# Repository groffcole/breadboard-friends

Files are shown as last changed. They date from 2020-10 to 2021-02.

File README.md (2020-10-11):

breadboard-friends
==================

A collection of cute breakout boards riding solderless breadboards, mostly for analog audio works

These PCB layouts and schematics are released under a Creative Commons cc-by-sa
3.0 license.

NOTE: This is a forked version of breadboard-friends and has two main differences from the original:
- There are two additional BBFs, one using Thonkiconn 3.5mm Jacks (bbf-thonkjacks) and another providing eurorack header with polarity protection for providing eurorack power to your breadboard from euro bus (bbf-europower). 
- This version has been updated to fit the power rails of the breadboards produced by [Assembly Specialist](http://www.assemblyspecialist.com/). The Assembly Specialist breadboard power rails have a wider spacing between them so the original BBFs do_not fit. Instead of 2x 10 pin DIL male headers for the power rails, use 4x 5 pin SIL male headers.

BBF-EUROPOWER Bill Of Materials (BOM)

- 2x 200ma PTC Poly Fuse or equivalent (or jumper wires if no fuse is required);
- 2x 10uF 25V Electrolytic Caps;
- 2x 1N5818 diodes or equivalent;
- 2x Ferrite Beads;
- 2x 10 Pin DIL male headers;
- 4x 5 pin SIL male headers.

BBF-THONKJACKS Bill Of Materials (BOM)

- 4x Thonkiconn Jacks;
- 1x 8 pin SIL female header;
- 4x 5 pin SIL male headers.

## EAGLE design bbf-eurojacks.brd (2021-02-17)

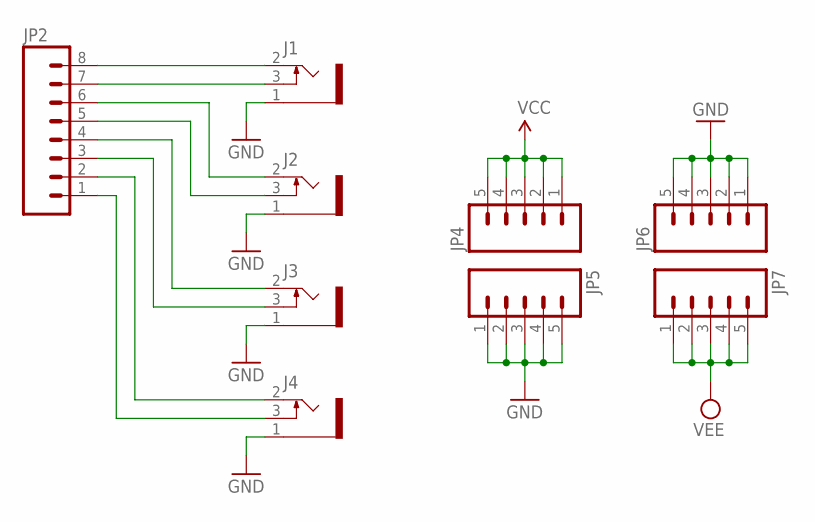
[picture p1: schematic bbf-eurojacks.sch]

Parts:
J1, J2, J3, J4: 1502_03SLOTTED; 1502_03_SLOTTED
JP2: M08; 1X08
JP4, JP5, JP6, JP7: M05PTH; 1X05

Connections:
GND: J1.1, J2.1, J3.1, J4.1, JP5.1, JP5.2, JP5.3, JP5.4, JP5.5, JP6.1, JP6.2, JP6.3, JP6.4, JP6.5
unnamed: J2.2, JP2.6
unnamed: J2.3, JP2.5
unnamed: J3.2, JP2.4
unnamed: J3.3, JP2.3
unnamed: J4.2, JP2.2
unnamed: J4.3, JP2.1
unnamed: J1.2, JP2.8
unnamed: J1.3, JP2.7
VCC: JP4.1, JP4.2, JP4.3, JP4.4, JP4.5
VEE: JP7.1, JP7.2, JP7.3, JP7.4, JP7.5

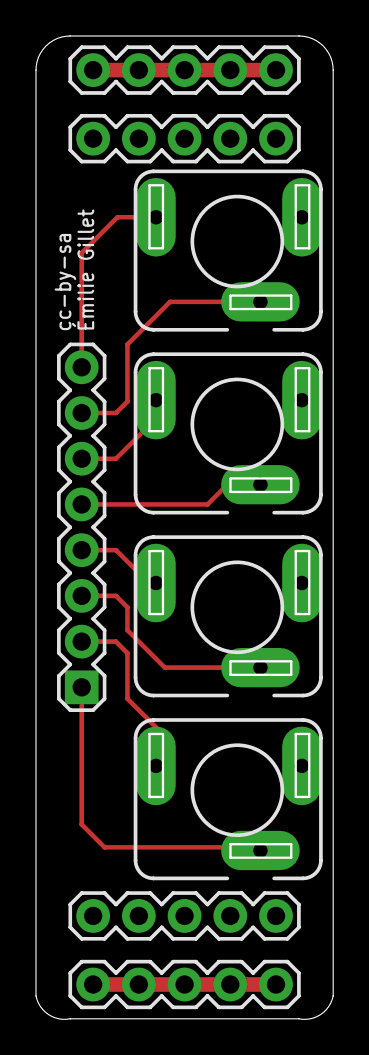
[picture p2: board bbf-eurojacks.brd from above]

Board: 2 copper layers, 16.5 x 54.6 mm, 9 parts (0 on the bottom side), 11 nets.

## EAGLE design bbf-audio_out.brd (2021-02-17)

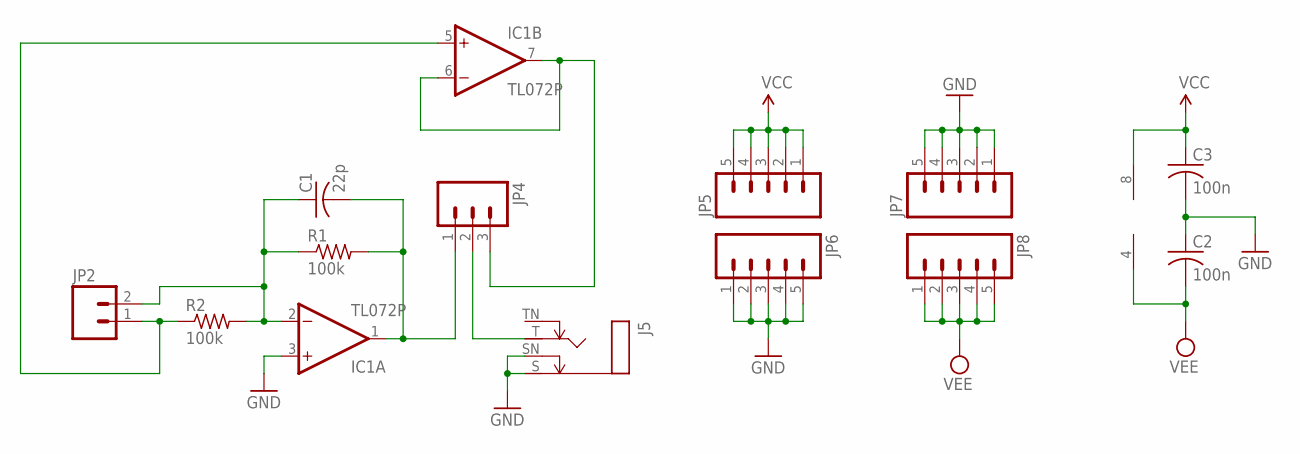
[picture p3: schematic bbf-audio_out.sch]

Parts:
C1: 22p; C025-025X050
C2, C3: 100n; C025-025X050
IC1: TL072P; DIL08
J5: MONOSWSLIM; NRJ4HF
JP2: M02PTH; 1X02
JP4: M03PTH; 1X03
JP5, JP6, JP7, JP8: M05PTH; 1X05
R1, R2: 100k; 0204/7

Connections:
GND: C2.1, C3.2, IC1.3 (+IN), J5.S, J5.SN, JP6.1, JP6.2, JP6.3, JP6.4, JP6.5, JP7.1, JP7.2, JP7.3, JP7.4, JP7.5
unnamed: C1.1, IC1.2 (-IN), JP2.2, R1.1, R2.2
unnamed: C1.2, IC1.1 (OUT), JP4.1, R1.2
unnamed: J5.T, JP4.2
unnamed: IC1.5 (+IN), JP2.1, R2.1
unnamed: IC1.6 (-IN), IC1.7 (OUT), JP4.3
VCC: C3.1, IC1.8 (V+), JP5.1, JP5.2, JP5.3, JP5.4, JP5.5
VEE: C2.2, IC1.4 (V-), JP8.1, JP8.2, JP8.3, JP8.4, JP8.5

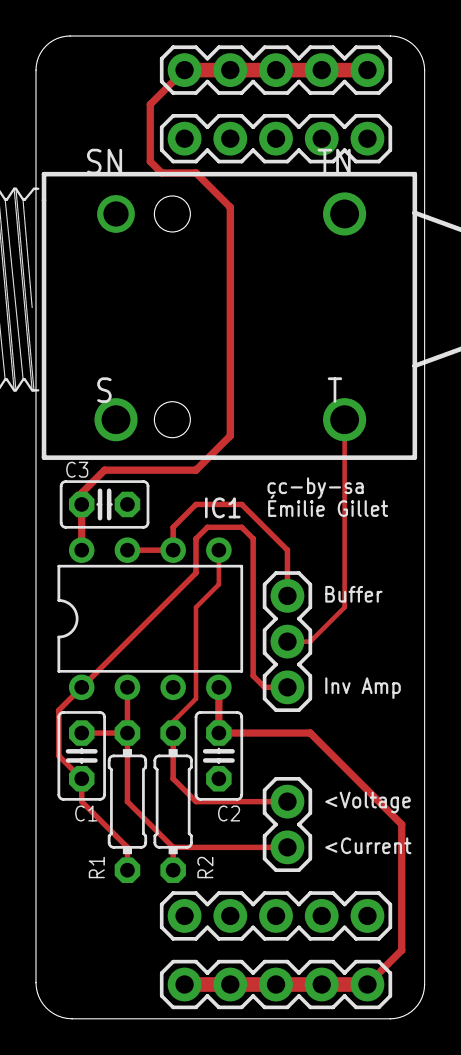
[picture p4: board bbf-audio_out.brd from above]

Board: 2 copper layers, 21.6 x 54.6 mm, 13 parts (0 on the bottom side), 8 nets.

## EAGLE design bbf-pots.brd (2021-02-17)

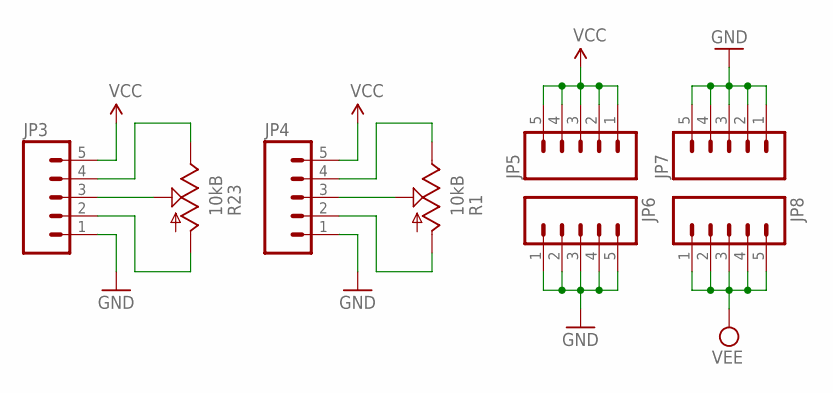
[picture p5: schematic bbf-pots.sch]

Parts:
JP3, JP4, JP5, JP6, JP7, JP8: M05PTH; 1X05
R1, R23: 10kB; ALPS_POT_VERTICAL

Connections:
GND: JP3.1, JP4.1, JP6.1, JP6.2, JP6.3, JP6.4, JP6.5, JP7.1, JP7.2, JP7.3, JP7.4, JP7.5
unnamed: JP3.4, R23.P$1 (E)
unnamed: JP3.3, R23.P$2 (S)
unnamed: JP3.2, R23.P$3 (A)
unnamed: JP4.4, R1.P$1 (E)
unnamed: JP4.3, R1.P$2 (S)
unnamed: JP4.2, R1.P$3 (A)
VCC: JP3.5, JP4.5, JP5.1, JP5.2, JP5.3, JP5.4, JP5.5
VEE: JP8.1, JP8.2, JP8.3, JP8.4, JP8.5

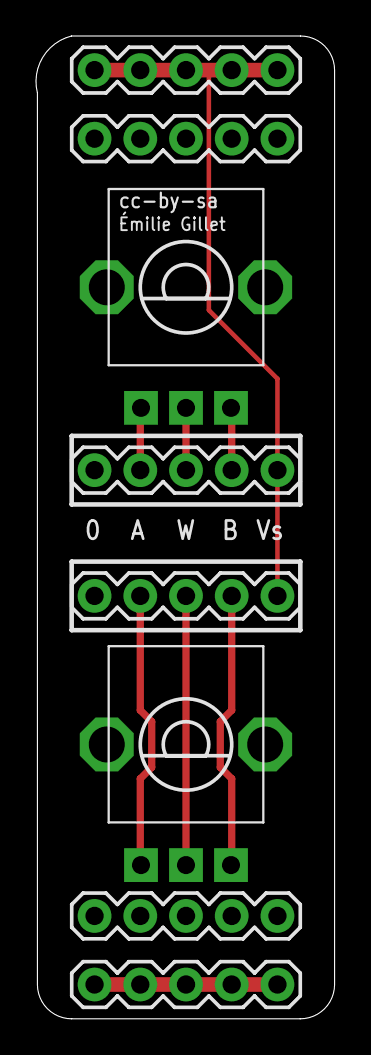
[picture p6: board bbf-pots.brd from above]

Board: 2 copper layers, 16.6 x 54.6 mm, 8 parts (0 on the bottom side), 9 nets.

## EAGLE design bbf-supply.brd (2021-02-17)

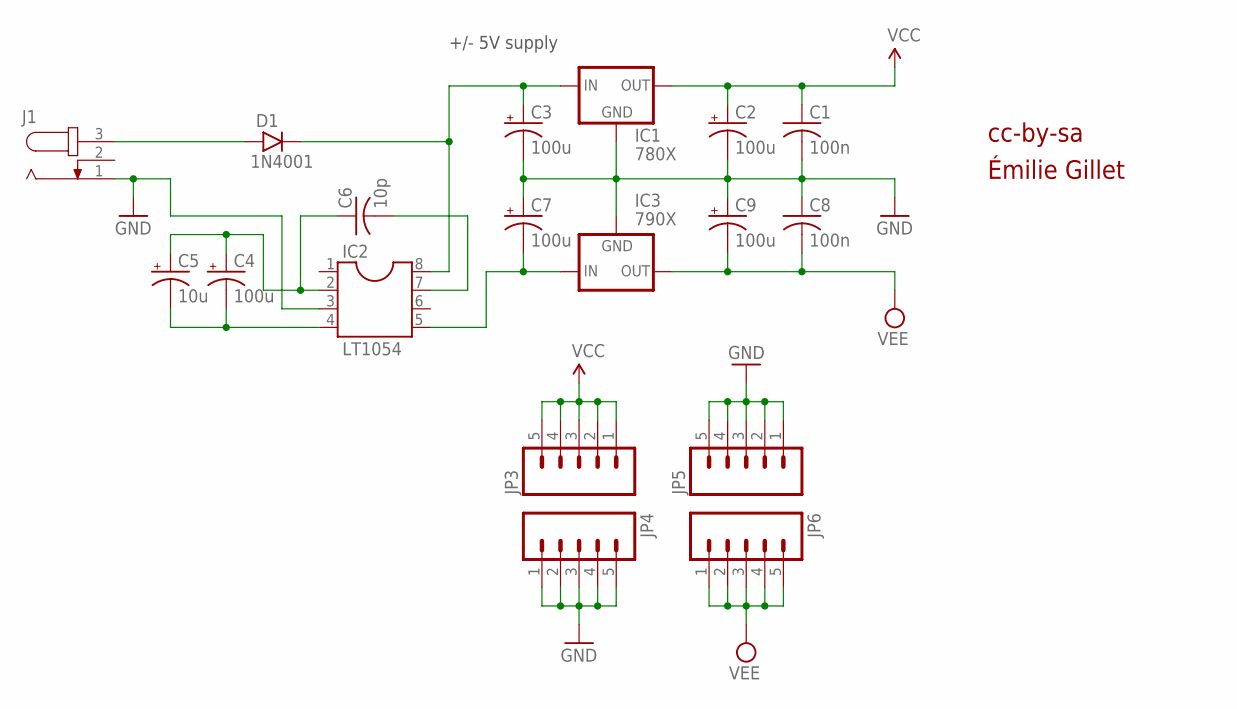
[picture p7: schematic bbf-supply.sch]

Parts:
C1, C8: 100n; C025-025X050
C2, C3, C7, C9: 100u; E2,5-7
C4: 100u; E2,5-6
C5: 10u; E2,5-5
C6: 10p; C025-025X050
D1: 1N4001; DO41-3
IC1: 780X; 78XXS
IC2: LT1054; DIL08
IC3: 790X; 79XXS
J1: JACK-PLUG2; SPC4078_BIG_HOLES
JP3, JP4, JP5, JP6: M05PTH; 1X05

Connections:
GND: C1.2, C2.-, C3.-, C7.+, C8.1, C9.+, IC1.GND, IC2.3, IC3.GND, J1.1, JP4.1, JP4.2, JP4.3, JP4.4, JP4.5, JP5.1, JP5.2, JP5.3, JP5.4, JP5.5
unnamed: D1.A, J1.3
unnamed: C3.+, D1.C, IC1.IN, IC2.8
unnamed: C4.+, C5.+, C6.1, IC2.2
unnamed: C4.-, C5.-, IC2.4
unnamed: C6.2, IC2.7
unnamed: C7.-, IC2.5, IC3.IN
VCC: C1.1, C2.+, IC1.OUT, JP3.1, JP3.2, JP3.3, JP3.4, JP3.5
VEE: C8.2, C9.-, IC3.OUT, JP6.1, JP6.2, JP6.3, JP6.4, JP6.5

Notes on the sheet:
cc-by-sa
Émilie Gillet
+/- 5V supply

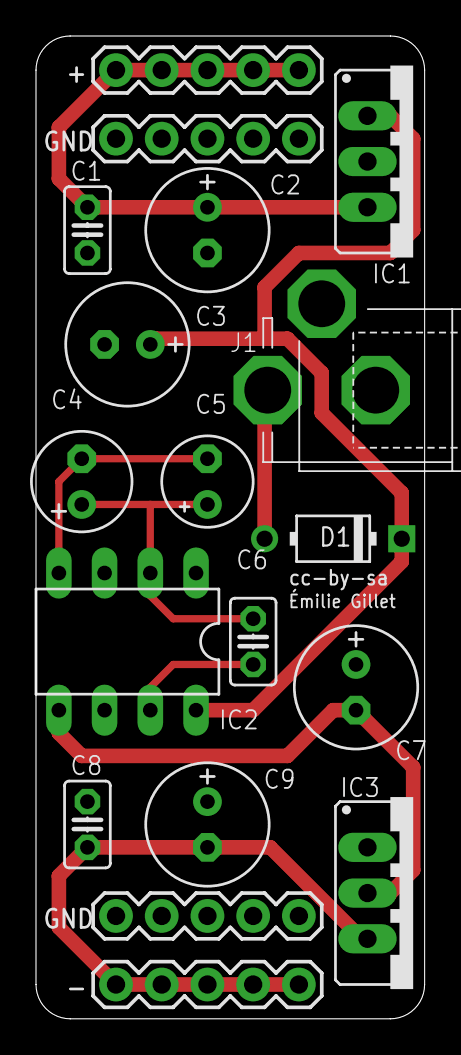
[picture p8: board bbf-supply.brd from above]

Board: 2 copper layers, 21.6 x 54.6 mm, 18 parts (0 on the bottom side), 9 nets.

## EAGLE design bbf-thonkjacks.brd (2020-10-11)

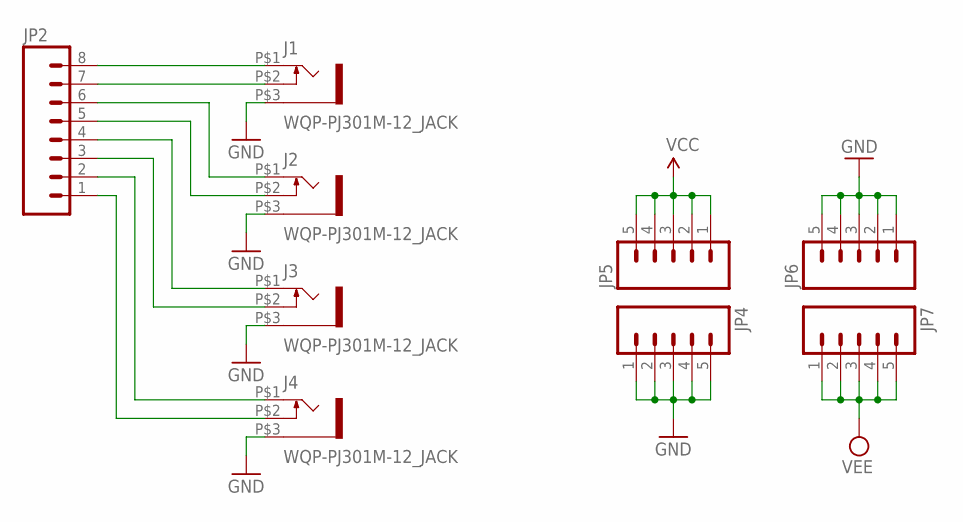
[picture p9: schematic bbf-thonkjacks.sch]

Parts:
J1, J2, J3, J4: WQP-PJ301M-12_JACK
JP2: M08; 1X08
JP4, JP5, JP6, JP7: M05PTH; 1X05

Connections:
GND: J1.P$3 (1), J2.P$3 (1), J3.P$3 (1), J4.P$3 (1), JP4.1, JP4.2, JP4.3, JP4.4, JP4.5, JP6.1, JP6.2, JP6.3, JP6.4, JP6.5
unnamed: J2.P$1 (2), JP2.6
unnamed: J2.P$2 (3), JP2.5
unnamed: J3.P$1 (2), JP2.4
unnamed: J3.P$2 (3), JP2.3
unnamed: J4.P$1 (2), JP2.2
unnamed: J4.P$2 (3), JP2.1
unnamed: J1.P$1 (2), JP2.8
unnamed: J1.P$2 (3), JP2.7
VCC: JP5.1, JP5.2, JP5.3, JP5.4, JP5.5
VEE: JP7.1, JP7.2, JP7.3, JP7.4, JP7.5

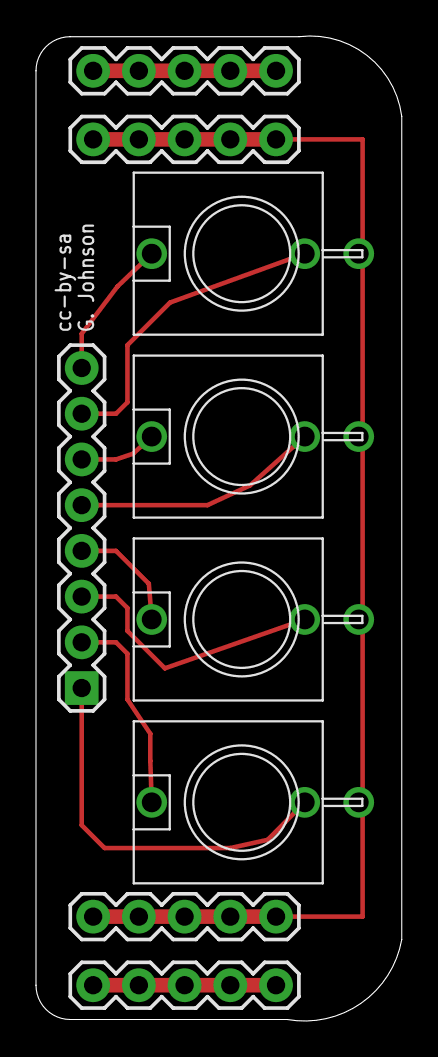
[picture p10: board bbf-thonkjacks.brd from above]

Board: 2 copper layers, 20.3 x 54.7 mm, 9 parts (0 on the bottom side), 11 nets.

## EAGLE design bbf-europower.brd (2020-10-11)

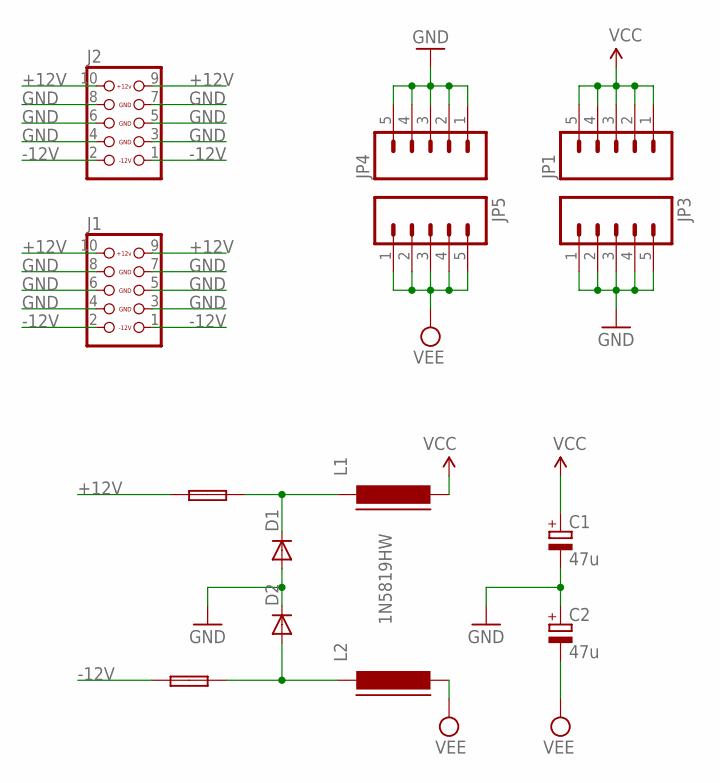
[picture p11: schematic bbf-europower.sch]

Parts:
+FUSE1: +FUSE; C050H075X075
-FUSE1: -FUSE; C050H075X075
C1, C2: 47u; E2-5
D1, D2: 1N5819HW; DO35-7
J1, J2: CON_HEADER_2X05-PTH; M2X5
JP1, JP3, JP4, JP5: M05PTH; 1X05
L1, L2: FERRITE-SHORT; FBS

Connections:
+12V: +FUSE1.1, J1.9, J1.10, J2.9, J2.10
-12V: -FUSE1.1, J1.1, J1.2, J2.1, J2.2
GND: C1.-, C2.+, D1.A, D2.C, J1.3, J1.4, J1.5, J1.6, J1.7, J1.8, J2.3, J2.4, J2.5, J2.6, J2.7, J2.8, JP3.1, JP3.2, JP3.3, JP3.4, JP3.5, JP4.1, JP4.2, JP4.3, JP4.4, JP4.5
unnamed: +FUSE1.2, D1.C, L1.1
unnamed: -FUSE1.2, D2.A, L2.1
VCC: C1.+, JP1.1, JP1.2, JP1.3, JP1.4, JP1.5, L1.2
VEE: C2.-, JP5.1, JP5.2, JP5.3, JP5.4, JP5.5, L2.2

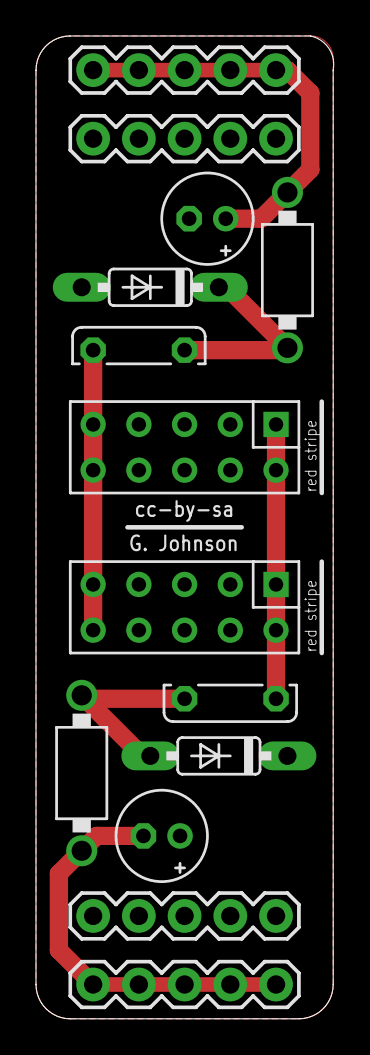
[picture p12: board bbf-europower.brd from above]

Board: 2 copper layers, 16.5 x 54.6 mm, 14 parts (0 on the bottom side), 7 nets.

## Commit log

2016-08-20 Add files via upload
    Through-hole versions of Thomas Hopman's revision of the bbf-europower.
    [bbf-europower.brd, bbf-europower.sch]
2016-08-20 Through-hole versions of Thomas Hopman's revision of the bbf-europower.
2020-09-25 adding the new 1x5 connector to ground - first attempt
    [bbf-europower.brd, bbf-europower.sch]
2020-09-25 the vcc with the farther away connector holes and wider board
    [bbf-europower.brd, bbf-europower.sch]
2020-09-25 almost there
    [bbf-europower.brd, bbf-europower.sch]
2020-09-25 finished first draft of europower
    [bbf-europower.brd]
2020-10-05 make the original eurojacks rails wider
    [bbf-eurojacks.brd, bbf-eurojacks.sch]
2020-10-05 thonkiconn jacks wider
    [bbf-thonkjacks.brd, bbf-thonkjacks.sch]
2020-10-05 pots more wider
    [bbf-pots.brd, bbf-pots.sch]
2020-10-05 audio out more wider
    [bbf-audio_out.brd, bbf-audio_out.sch]
2020-10-05 working on supply more wider
    [bbf-supply.brd, bbf-supply.sch]
2020-10-11 supply more wider
    [bbf-supply.brd]
2020-10-11 thonkjacks + and - symbols for the power rails
    [bbf-thonkjacks.brd]
2020-10-11 remove the + and - symbols from thonkjacks
    [bbf-thonkjacks.brd]
2020-10-11 make the power rails trace a little less wider
    [bbf-eurojacks.brd]
2021-02-17 update names on boards and schematics
    [bbf-audio_out.brd, bbf-eurojacks.brd, bbf-pots.brd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]

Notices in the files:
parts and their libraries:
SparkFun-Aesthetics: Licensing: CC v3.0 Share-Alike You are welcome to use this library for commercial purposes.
